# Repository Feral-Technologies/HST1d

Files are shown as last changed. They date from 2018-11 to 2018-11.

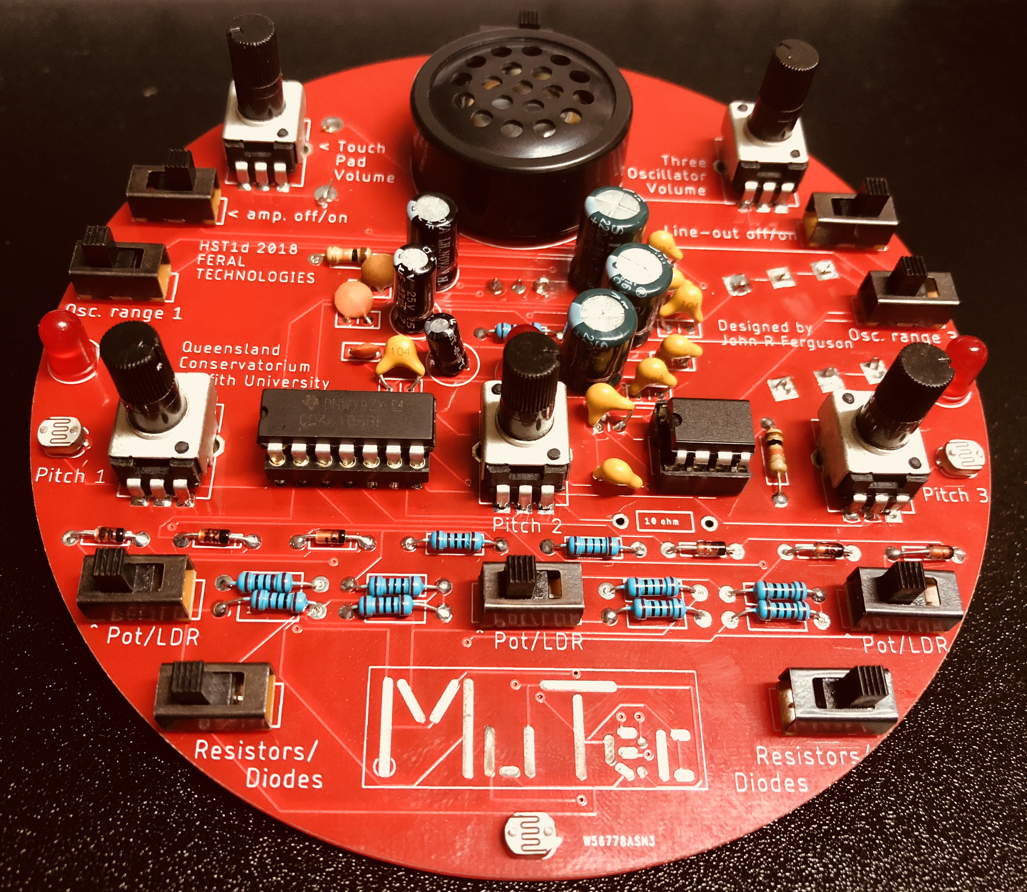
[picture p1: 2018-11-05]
IMG_1294.jpg

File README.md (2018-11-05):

HST1d FERAL TECHNOLOGIES AKA The Music Technology Frisbee (as christened by Electronic Instruments students 2018) is a six-voice portable and battery powered synthesiser based around a 40106 (Hex Schmitt-Trigger). 

Three voices are operated via resistive-touch on the MuTec lettering;

Three voices can be either light-sensitive (photocells) or controlled via potentiometers, the control method is individually switchable for each of these three voices;

The range of the three light/potentiometer-controlled voices is switchable high/low;

Lighting/pitch control is laid out horizontally across the board while from an output perspective the instrument is divided in half down the middle, with two separate volume controls: one for the three touch sensitive voices and the other for the three light/potentiometer voices;

The three individual voices that make up each of the two halves of the instrument can either be mixed via diodes or resistors (switchable), which offers further timbral manipulation;

Output is via mono ¼ inch jack socket on the rear (along with the off/on switch) and/or the onboard amplifier/speaker combination using an LM386 (switchable, and both can be used simultaneously, though there’s no buffering so this can impact tone–I should add an op-amp in future);

Power is via 9-volt battery which clips into a socket on the rear, this also makes the whole thing stable and sit nicely/angled towards the performer when used as as a desktop instrument;

LEDs articulate interactions with the touch-sensitive side of the circuit;

Two of the LEDs on the touch circuit are deliberately placed near the photocells that control two of the other voices, if desired these can be bent towards each other (and even taped together/mounted in a straw) for vactrol fun and interaction.

In case anyone actually try to build this it’s worth noting this I had to make my own footprints for the switches as I had bought a large quantity very cheaply and the spacing was not quite what I anticipated, some standard switches do not fit – always best to print out and check components by pushing through the paper! (I learned this the hard way…..)

See HST1d_Feral_Technologies_2018.pdf for full build documentation with step-by-step build instructions, parts list, and a photograph of each stage (this was made for my 2018 teaching of 2710QCM Electronic Instruments @ QCGU).

More information 
http://www.johnrobertferguson.com/hst1d-feral-technologies/

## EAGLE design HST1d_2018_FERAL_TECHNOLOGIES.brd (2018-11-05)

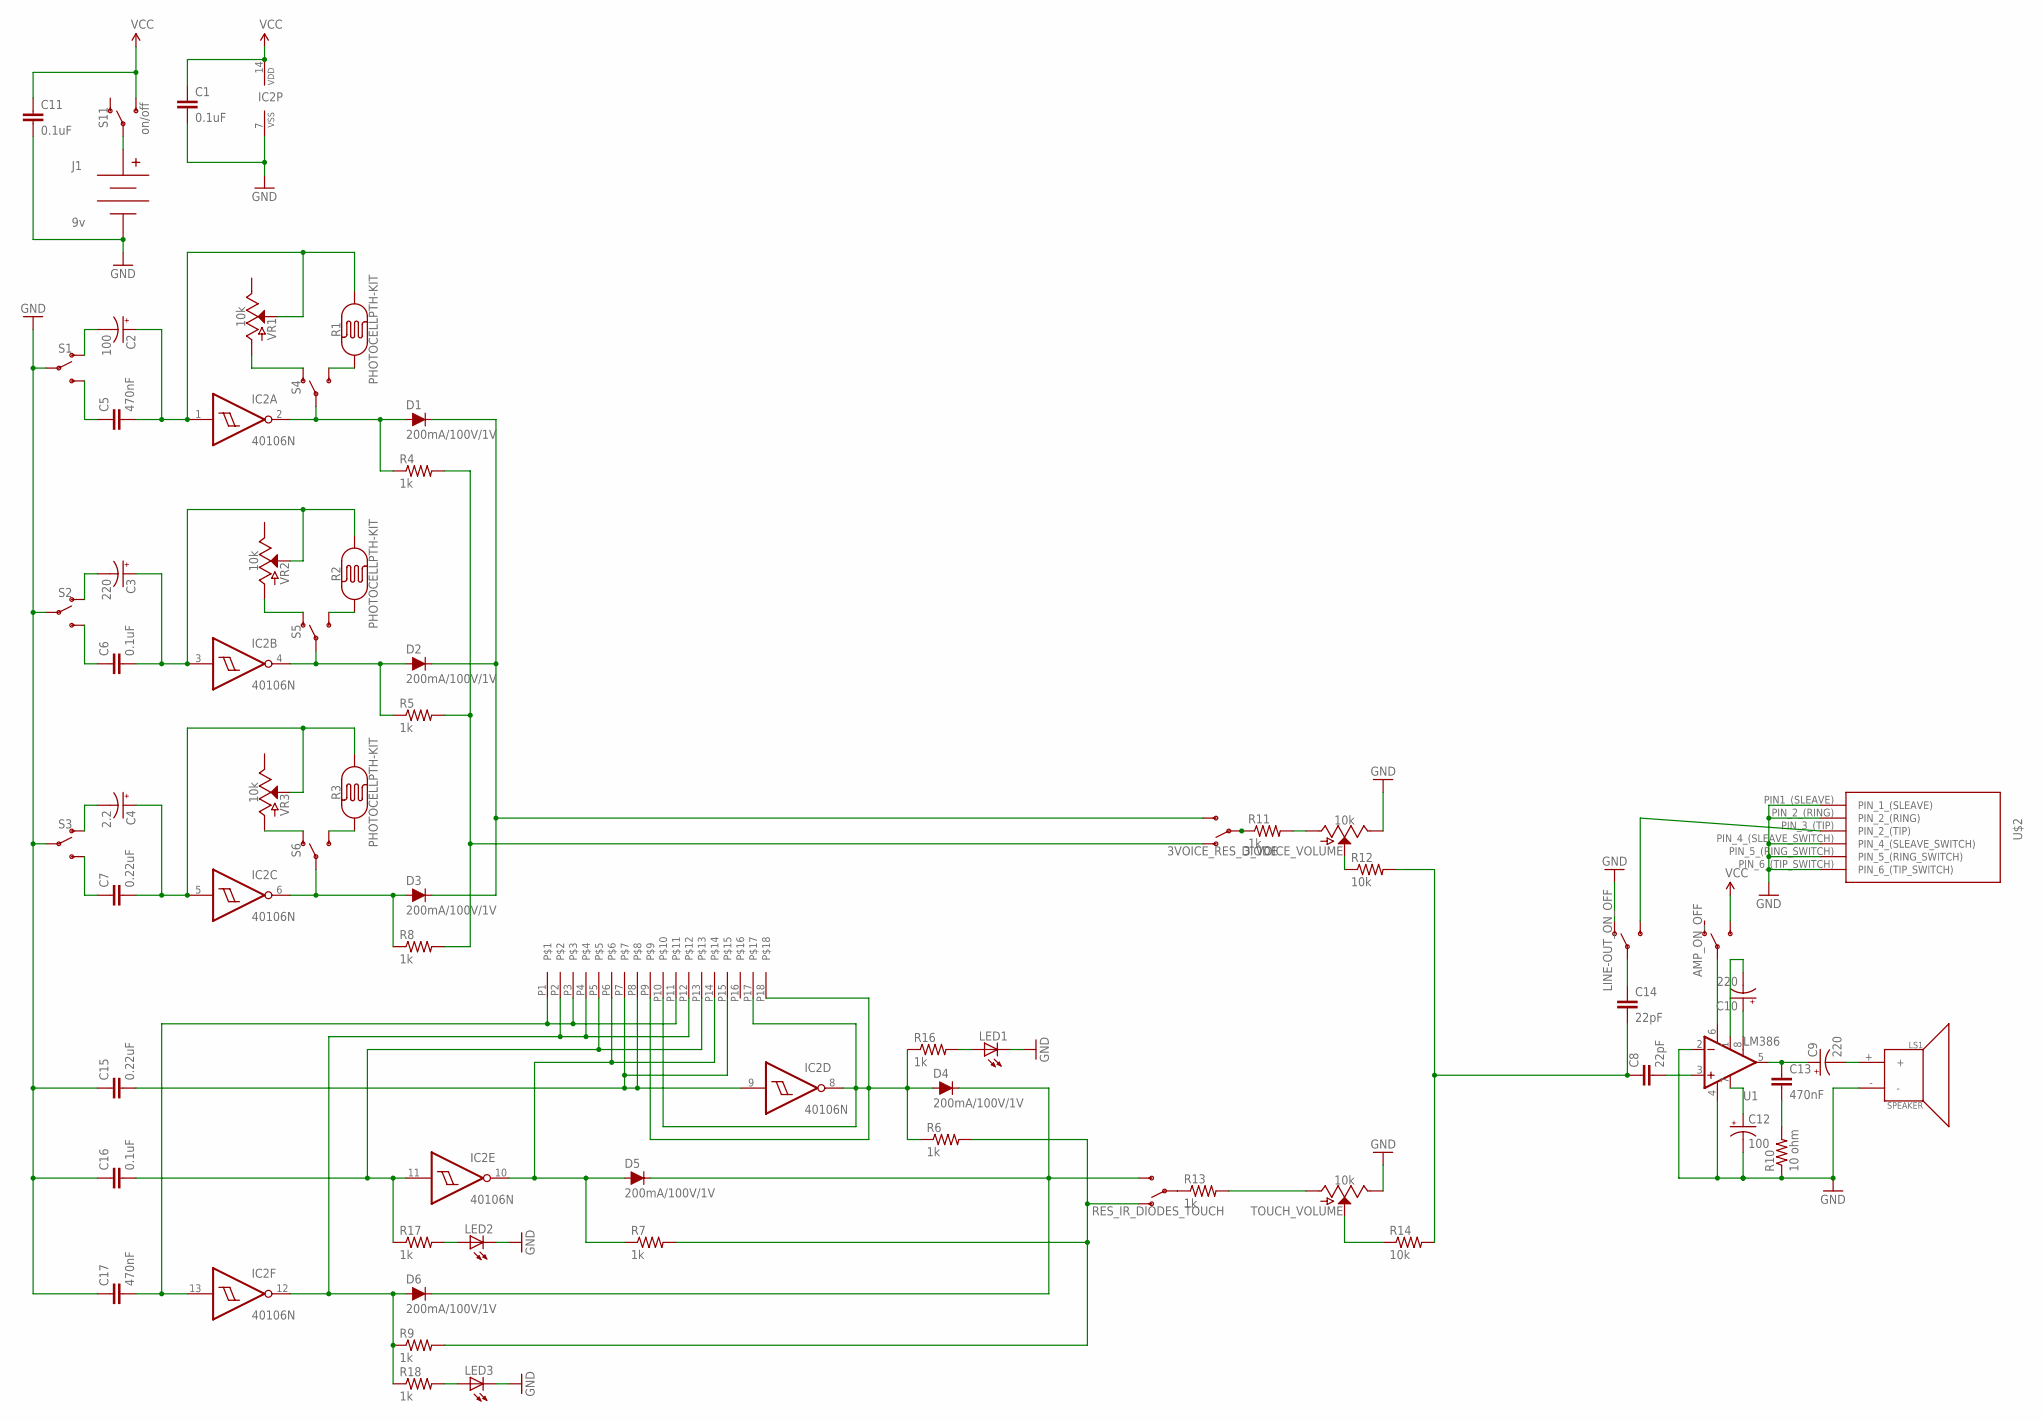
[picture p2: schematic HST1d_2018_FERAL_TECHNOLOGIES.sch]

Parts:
3VOICE_RES_DIODE: SWITCH-SPDT-PTH-11.6X4.0MM; SWITCH_SPDT_PTH_11.6X4.0MM
3_VOICE_VOLUME: 10k; POT-PTH-ALPS
AMP_ON_OFF: SWITCH-SPDT-PTH-11.6X4.0MM; SWITCH_SPDT_PTH_11.6X4.0MM
C1, C6, C11, C16: 0.1uF; CAP-PTH-SMALL-KIT
C2, C12: 100; CPOL-RADIAL-100UF-25V
C3, C9, C10: 220; CPOL-RADIAL-100UF-25V
C4: 2.2; CPOL-RADIAL-100UF-25V
C5, C17: 470nF; CAP-PTH-SMALL-KIT
C7, C15: 0.22uF; CAP-PTH-SMALL-KIT
C8, C14: 22pF; CAP-PTH-2.54
C13: 470nF; CAP-PTH-SMALLEZ
D1, D2, D3, D4, D5, D6: 200mA/100V/1V; DIODE-1N4148
IC2: 40106N; DIL14
J1: 9v; BC9VPC
LED1, LED2, LED3: LED5MM
LINE-OUT_ON_OFF: SWITCH-SPDT-PTH-11.6X4.0MM; SWITCH_SPDT_PTH_11.6X4.0MM
LS1: SPEAKER; PCB_MOUNT_SPEAKER
R1, R2, R3: PHOTOCELLPTH-KIT; PHOTOCELL-KIT
R4, R5, R6, R7, R8, R9, R11, R13, R16, R17, R18: 1k; AXIAL-0.4
R10: 10 ohm; AXIAL-0.4
R12, R14: 10k; AXIAL-0.4
RES_IR_DIODES_TOUCH: SWITCH-SPDT-PTH-11.6X4.0MM; SWITCH_SPDT_PTH_11.6X4.0MM
S1, S2, S3, S4, S5, S6: SWITCH-SPDT-PTH-11.6X4.0MM; SWITCH_SPDT_PTH_11.6X4.0MM
S11: on/off; SWITCH_SPDT_PTH_11.6X4.0MM
TOUCH_VOLUME: 10k; POT-PTH-ALPS
U1: LM386; DIP08
U$1: MT_TOUCH_POINT; TOUCH_POINT
U$2: 0.25_INCH_TRS_SWITCHED_AUDIO_SOCKET; 0.25INCH_AUDIO_SOCKET
VR1, VR2, VR3: 10k; POT-PTH-ALPS

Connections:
GND: 3_VOICE_VOLUME.P$1 (E), C1.2, C11.2, C12.2 (-), C15.1, C16.1, C17.1, IC2.7 (VSS), J1.V-, LED1.K (C), LED2.K (C), LED3.K (C), LINE-OUT_ON_OFF.1 (O), LS1.-, R10.P$1 (1), S1.2, S2.2, S3.2, TOUCH_VOLUME.P$1 (E), U1.2 (-IN), U1.4 (V-), U$2.PIN1_(SLEAVE) (PIN_1_(SLEAVE)), U$2.PIN_2_(RING), U$2.PIN_4_(SLEAVE_SWITC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, U$2.PIN_5_(RING_SWITCH), U$2.PIN_6_(TIP_SWITCH)
unnamed: C2.2 (-), S1.1 (O)
unnamed: C3.2 (-), S2.1 (O)
unnamed: C4.2 (-), S3.1 (O)
unnamed: C5.1, S1.3 (S)
unnamed: C2.1 (+), C5.2, IC2.1 (I), R1.2, VR1.P$2 (S)
unnamed: C6.1, S2.3 (S)
unnamed: D2.A, IC2.4 (O), R5.P$1 (1), S5.2
unnamed: C7.1, S3.3 (S)
unnamed: R1.1, S4.3 (S)
unnamed: D3.A, IC2.6 (O), R8.P$1 (1), S6.2
unnamed: S4.1 (O), VR1.P$3 (A)
unnamed: D1.A, IC2.2 (O), R4.P$1 (1), S4.2
unnamed: R6.P$2 (2), R7.P$2 (2), R9.P$2 (2), RES_IR_DIODES_TOUCH.1 (O)
unnamed: S5.1 (O), VR2.P$3 (A)
unnamed: R2.1, S5.3 (S)
unnamed: R3.1, S6.3 (S)
unnamed: C3.1 (+), C6.2, IC2.3 (I), R2.2, VR2.P$2 (S)
unnamed: C4.1 (+), C7.2, IC2.5 (I), R3.2, VR3.P$2 (S)
unnamed: 3_VOICE_VOLUME.P$2 (S), R12.P$1 (1)
unnamed: 3VOICE_RES_DIODE.3 (S), D1.C, D2.C, D3.C
unnamed: LINE-OUT_ON_OFF.3 (S), U$2.PIN_3_(TIP) (PIN_2_(TIP))
unnamed: R14.P$1 (1), TOUCH_VOLUME.P$2 (S)
unnamed: 3VOICE_RES_DIODE.1 (O), R4.P$2 (2), R5.P$2 (2), R8.P$2 (2)
unnamed: C15.2, IC2.9 (I), U$1.P7, U$1.P8, U$1.P15
unnamed: C14.1, LINE-OUT_ON_OFF.2
unnamed: LED2.A, R17.P$2 (2)
unnamed: C9.1 (+), C13.1, U1.5 (OUT)
unnamed: D4.A, IC2.8 (O), R6.P$1 (1), R16.P$1 (1), U$1.P9, U$1.P10, U$1.P17, U$1.P18
unnamed: J1.V+, S11.2
unnamed: D5.A, IC2.10 (O), R7.P$1 (1), U$1.P6, U$1.P14
unnamed: R13.P$2 (2), TOUCH_VOLUME.P$3 (A)
unnamed: C8.2, U1.3 (+IN)
unnamed: C9.2 (-), LS1.+
unnamed: C12.1 (+), U1.7 (BP)
unnamed: S6.1 (O), VR3.P$3 (A)
unnamed: C10.1 (+), U1.8 (GAIN)
unnamed: C10.2 (-), U1.1 (GAIN)
unnamed: C13.2, R10.P$2 (2)
unnamed: C8.1, C14.2, R12.P$2 (2), R14.P$2 (2)
unnamed: D6.A, IC2.12 (O), R9.P$1 (1), R18.P$1 (1), U$1.P2, U$1.P4, U$1.P12
unnamed: AMP_ON_OFF.2, U1.6 (V+)
unnamed: LED1.A, R16.P$2 (2)
unnamed: D4.C, D5.C, D6.C, RES_IR_DIODES_TOUCH.3 (S)
unnamed: C16.2, IC2.11 (I), R17.P$1 (1), U$1.P5, U$1.P13
unnamed: R13.P$1 (1), RES_IR_DIODES_TOUCH.2
unnamed: C17.2, IC2.13 (I), U$1.P1, U$1.P3, U$1.P11
unnamed: LED3.A, R18.P$2 (2)
unnamed: 3_VOICE_VOLUME.P$3 (A), R11.P$2 (2)
RES_OR_DIODES_3_VOICES: 3VOICE_RES_DIODE.2, R11.P$1 (1)
VCC: AMP_ON_OFF.3 (S), C1.1, C11.1, IC2.14 (VDD), S11.3 (S)

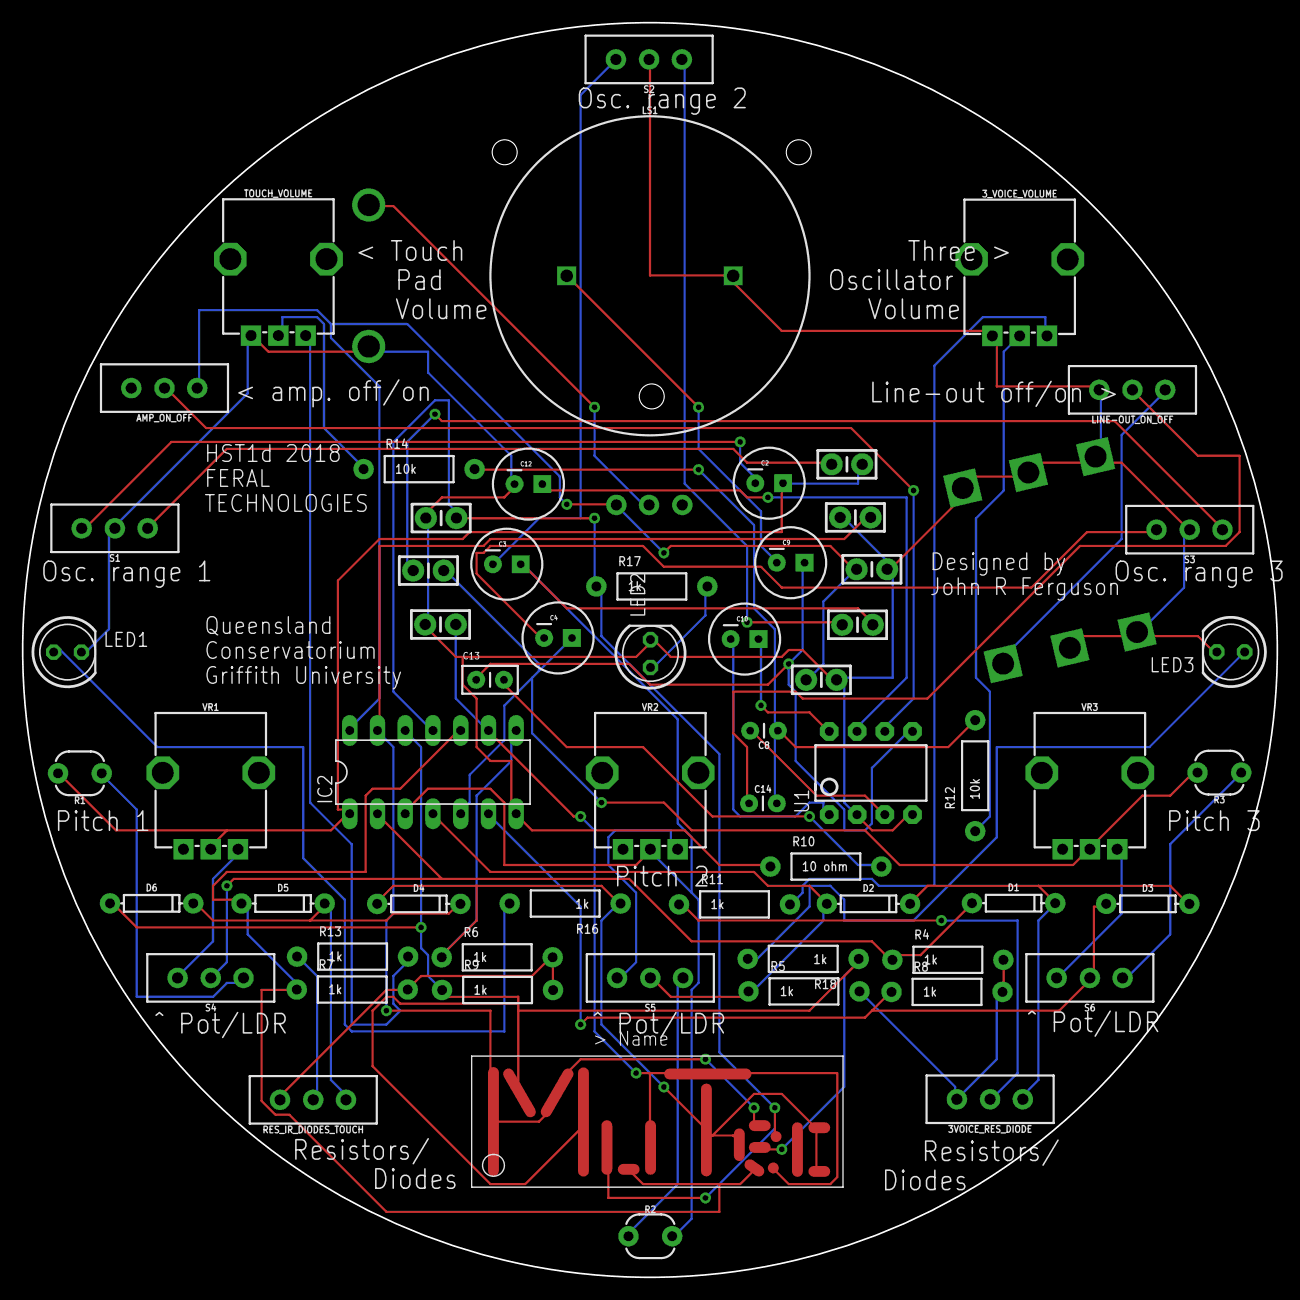
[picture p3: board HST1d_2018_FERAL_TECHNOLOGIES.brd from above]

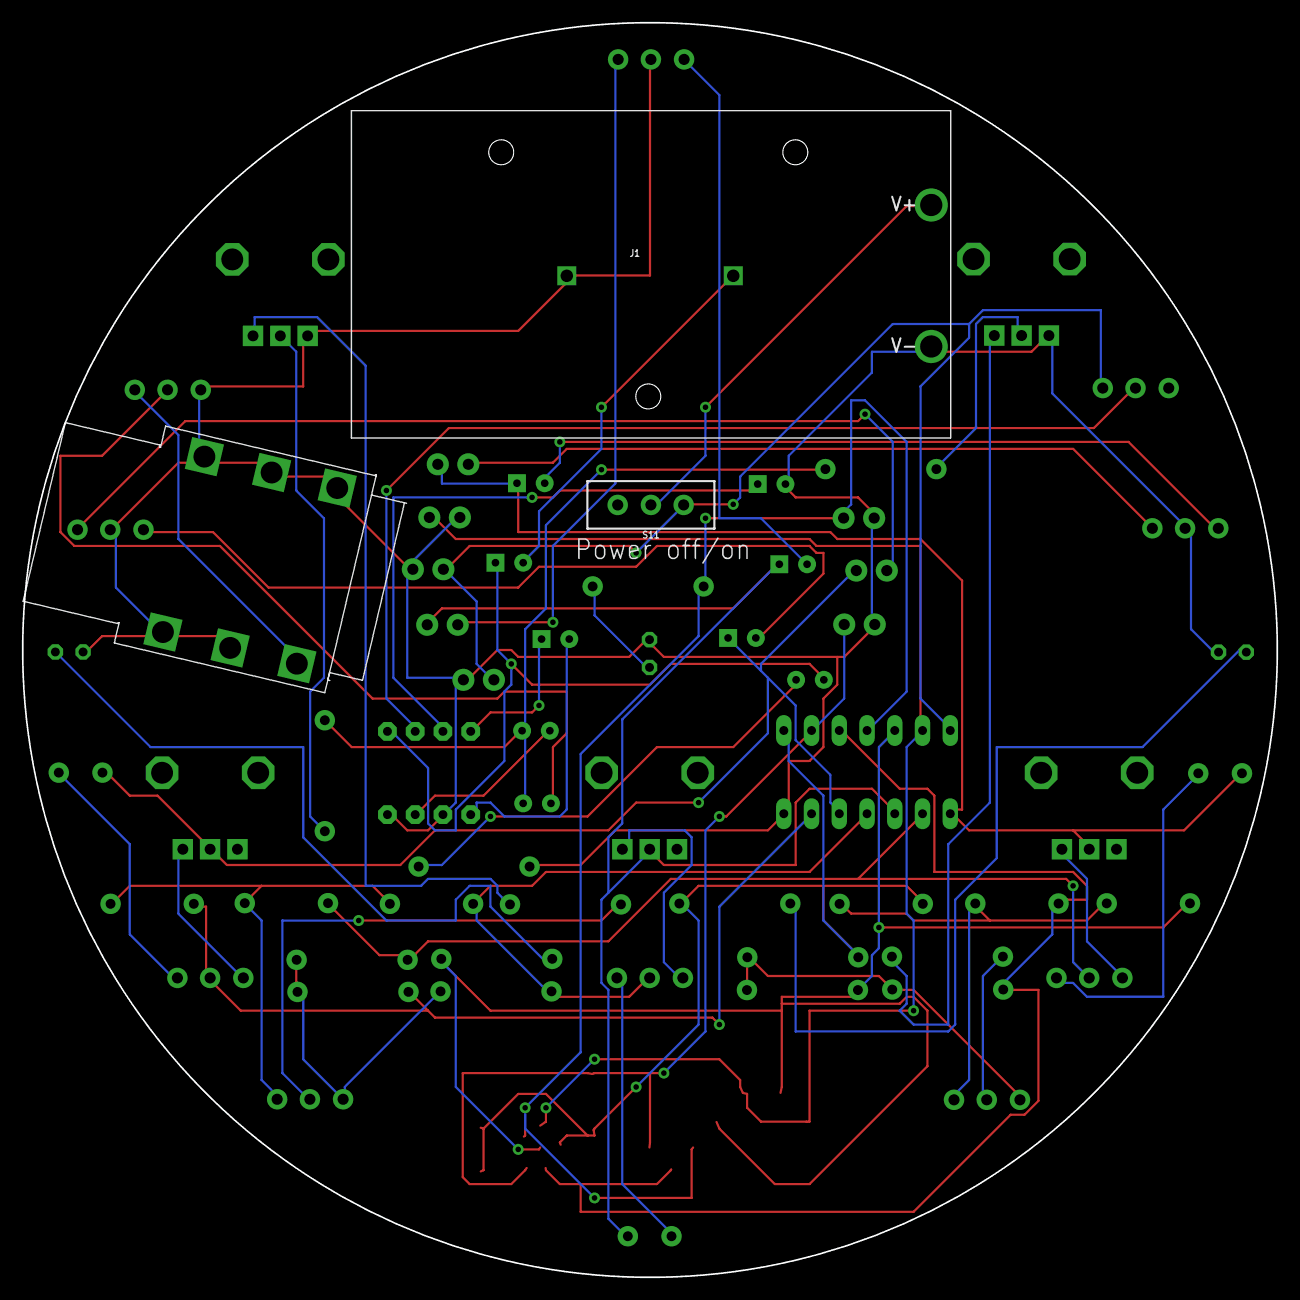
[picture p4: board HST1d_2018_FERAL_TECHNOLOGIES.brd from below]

Board: 2 copper layers, 114.9 x 114.9 mm, 65 parts (3 on the bottom side), 51 nets.

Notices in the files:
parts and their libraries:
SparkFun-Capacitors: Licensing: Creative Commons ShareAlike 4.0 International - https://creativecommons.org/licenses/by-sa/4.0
